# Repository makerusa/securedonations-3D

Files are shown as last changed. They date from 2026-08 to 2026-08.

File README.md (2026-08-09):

# Secure Donations — 3D-Printable Donation Box

Open design files to build your own **contactless donation box** for the free
[Secure Donations](https://securedonations.net) app. Print the box, add a phone
running the app plus a Square reader, and you have a tap-to-give kiosk for your
mosque, church, temple, or community — funded into **your own Square account**,
with no cut taken from donations.

> **New here?** Get the app first — it's free:
> [**Get it on Google Play**](https://play.google.com/store/apps/details?id=com.securedonations.terminal)

---

## What's in this repo

| File | What it is |
| --- | --- |
| `Secure Donations Box/Base/Secure Donations Box Base.stl` | The main body of the box — holds the phone and reader, with the donation slot. |
| `Secure Donations Box/Lid/Secure Donations Box Lid.stl` | The top lid, with the Secure Donations logo inset into it. |
| `Secure Donations Box/Lid/Secure Donations Box Logo - 1.stl` | Top section of the inset logo (printed in a contrast color). |
| `Secure Donations Box/Lid/Secure Donations Box Logo - 2.stl` | Bottom section of the inset logo (printed in a contrast color). |

## What else you'll need

- **A phone** running the Secure Donations app — the box is sized for the
  **Motorola Moto G Play (2024)**, available free on
  [Google Play](https://play.google.com/store/apps/details?id=com.securedonations.terminal).
- **A Square reader** — fits either model; the **2nd-generation** contactless +
  chip reader is recommended.
- **6 × magnets, 5 mm × 3 mm** — press-fit into the base and lid for a magnetic
  closure. *(Mind the polarity so the lid and base attract.)*
- **1 × steel rod, 3 mm × 180 mm** — pushed through the lid/base hinge to
  interlock the two halves.
- **PLA filament** — roughly **360 g** total (see below), plus a contrast color
  (ideally **gold**) for the logo.

Don't want to print and assemble it yourself? You can order a **Ready-Made Kit**
(everything included, pre-configured) or a **Provisioned Phone** at
[securedonations.net](https://securedonations.net).

## Printing

Material is **PLA** with your slicer's **default settings** — no special profile
needed.

| Part | Filament | Time (Bambu A1) | Supports |
| --- | --- | --- | --- |
| Base | ~260 g | — | **None** |
| Lid (with logo) | just under 100 g | ~9 h 37 m | **Tree supports** |

### Printing the lid + logo (important)

The lid and both logo pieces are designed to print together as one multi-color
part:

1. Open/import **all three files in the `Lid` folder together** in your slicer.
2. When prompted **"Load these files as a single object with multiple parts?"**,
   click **Yes**.
3. In the **Prepare** tab, select the objects and set **Logo - 1** and
   **Logo - 2** to the same contrast color — **gold** looks best.
4. Enable **tree supports** (the design has some overhangs that print best with
   them).

The **base** prints on its own with **no supports**.

## Assembly

1. Print the **Base** (no supports) and the **Lid + logo** (tree supports, logo
   in gold).
2. Press the **six 5 × 3 mm magnets** into the recesses in the base and lid —
   check polarity so the lid closes and holds.
3. Push the **3 mm × 180 mm steel rod** through the aligned hinge on the lid and
   base to link them together.
4. Place the **Moto G Play (2024)** and your **Square reader** into the base.
5. Open the Secure Donations app, sign in, connect your Square account, and
   you're ready to collect.

## Also available on

- Printables · MakerWorld · Thingiverse — *listings coming soon.*

## License

Released under **[Creative Commons Attribution-NonCommercial-ShareAlike 4.0 (CC BY-NC-SA 4.0)](https://creativecommons.org/licenses/by-nc-sa/4.0/)** — see [`LICENSE`](LICENSE).

You're free to use, modify, and share these files — including remixes — as long as you:

- **Give attribution** to Secure Donations,
- **Don't use them commercially** — no selling the files or the printed boxes — without our permission, and
- **Share your remixes under the same license**, so the whole community benefits.

**Want to sell prints or use this commercially?** We're open to it — reach out via
[securedonations.net](https://securedonations.net) for a commercial license.

---

Built one? We'd love to see it — share it with your community and let us know at
[securedonations.net](https://securedonations.net).

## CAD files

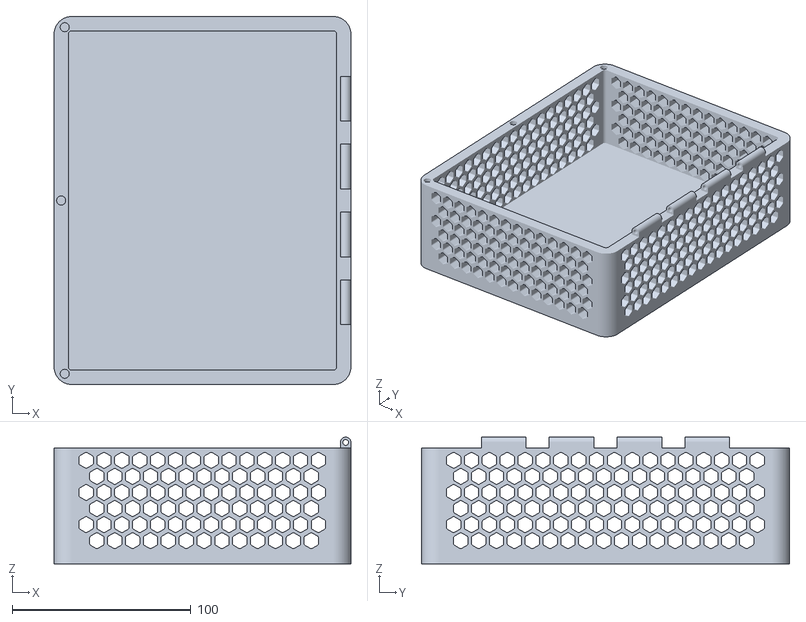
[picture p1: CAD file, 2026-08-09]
Secure Donations Box/Base/Secure Donations Box Base.stl
166.2 x 206.0 x 71.0

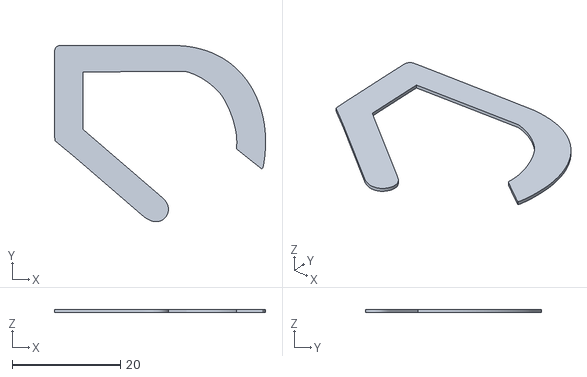
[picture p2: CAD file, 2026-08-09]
Secure Donations Box/Lid/Secure Donations Box Logo - 2.stl
38.9 x 32.5 x 0.5

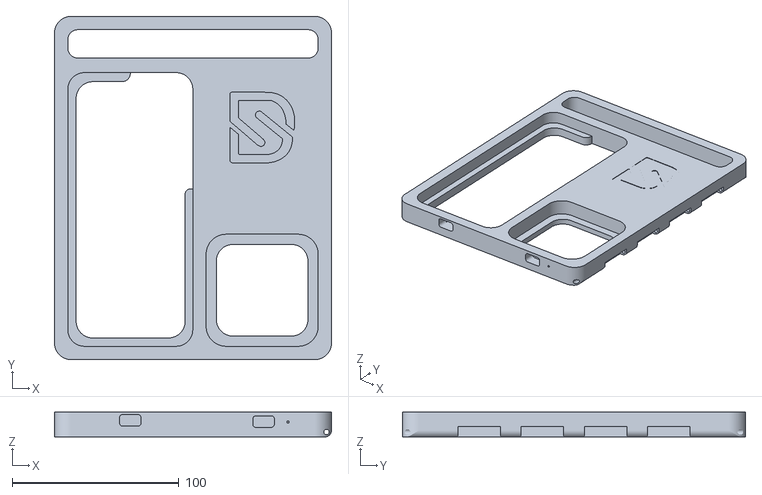
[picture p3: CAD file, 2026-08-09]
Secure Donations Box/Lid/Secure Donations Box Lid.stl
166.2 x 206.0 x 15.0

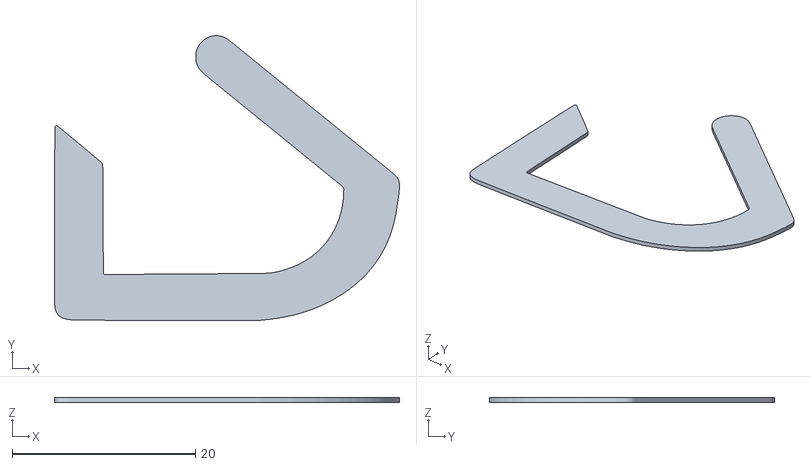
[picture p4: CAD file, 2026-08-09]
Secure Donations Box/Lid/Secure Donations Box Logo - 1.stl
37.7 x 31.1 x 0.5

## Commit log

2026-08-09 Add Secure Donations Box 3D model files
    Add 3D-printable assets for the Secure Donations Box: Base, Lid, and parts of the Logo as STL binaries. These files provide the printable components needed to assemble the donation box.
    [Secure Donations Box Base.stl, Secure Donations Box Lid.stl, Secure Donations Box Logo - 1.stl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]
2026-08-09 docs: add build README, .gitignore; remove committed .DS_Store files
    Add a full build guide (bill of materials, print settings, lid+logo
    multi-color workflow, assembly, CC BY-SA 4.0 license) and stop tracking
    macOS .DS_Store junk.
2026-08-09 docs: switch license to CC BY-NC-SA 4.0 and add LICENSE file
    Block commercial use (selling the files or printed boxes) without a separate
    commercial license, while keeping the design free to use and remix
    non-commercially with attribution and share-alike. Add an explicit
    commercial-licensing contact.
